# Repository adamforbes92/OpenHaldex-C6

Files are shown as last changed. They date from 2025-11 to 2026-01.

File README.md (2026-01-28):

# OpenHaldex - ESP32 C6
An open-source Generation 1, 2 & 4 Haldex Controller which originates/is a fork from ABangingDonk's 'OpenHaldex T4'.  It has been extended into Gen2 and Gen4 variants, with Gen3 and Gen5 currently unsupported - CAN reads of these systems would be awesome!

Originally based on the Teensy 4.0; the ESP32 C6 features two TWAI (CAN) interfaces as well as WiFi and Bluetooth support; which makes it an ideal candidate for easier interfacing.

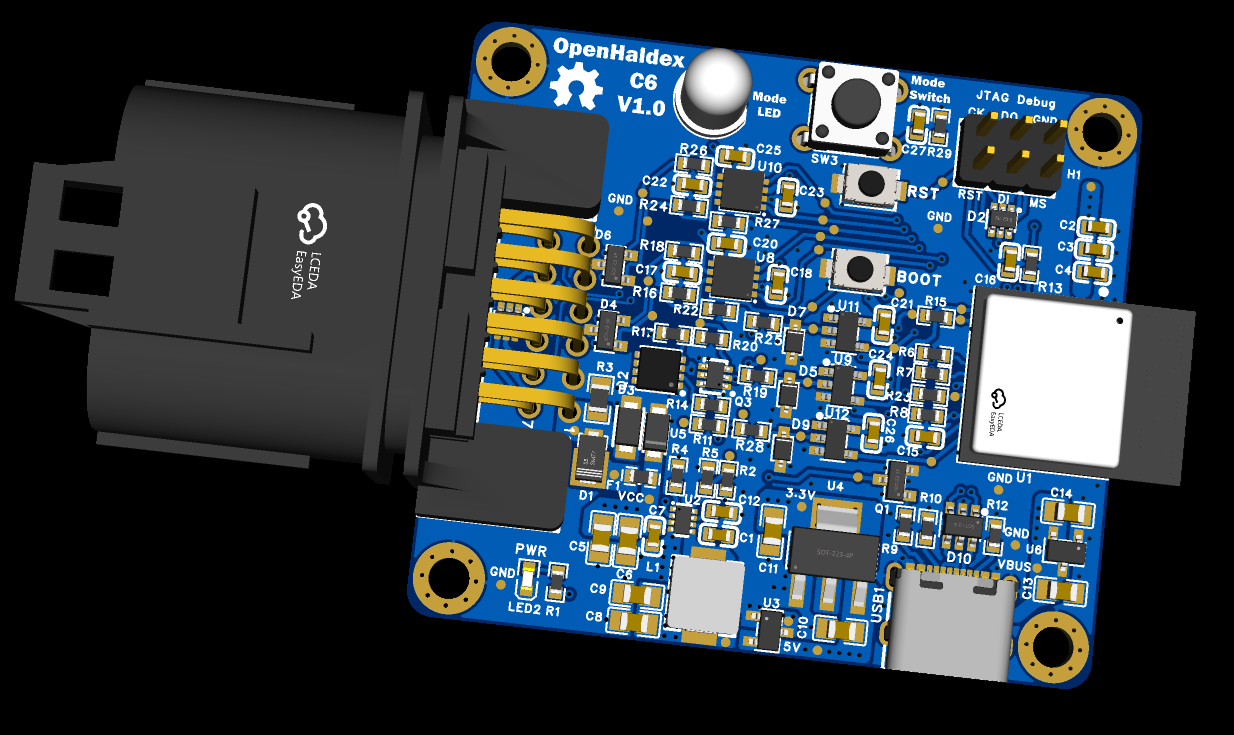
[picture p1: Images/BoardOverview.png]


### Purchase
If you want to purchase an assembled OpenHaldex C6 controller, you can do so here: [OpenHaldex C6 Controller - Forbes Automotive](https://forbes-automotive.com/products/openhaldex-controller)

### Concept
The basis of the module is to act as a middle man - read the incoming CAN frames destined for the OEM Haldex controller, and, if required, adjust these messages to 'trick' the Haldex into thinking more (or less) lock is required.  

Generation 1, 2 and 4 are all available as 'standalone' systems - which means that no other ECUs have to be present and OpenHaldex will create the necessary frames for Haldex operation.

### ESP32 C6
The ESP32 C6 features two TWAI controllers - which allows CANBUS messages to be read, processed and re-transmitted towards the Haldex.  It also supports WiFi and Bluetooth - which makes on-the-fly configuration changes possible.  

The original Teensy had an external HC-05 Bluetooth chip which is limited support wise - hence the decision to move to the ESP32.

### The Modes
The controller allows for 5 main modes: Stock (act as OEM), FWD (zero lock), 7525 (25% lock), 6040 (40% lock) and 5050 (100% lock) at the Haldex differential.  Generation 1, 2 and 4 have been tested on the bench to allow for a full understanding of what the stock CAN messages look like & therefore what messages need to be editted / created. 

These modes are displayed as colours using the 5mm PCB LED: Red (Stock), Green (FWD), Cyan (7525), Hot Pink (6040) and Blue (5050).  Custom modes are white.

#### Custom Modes
Custom modes allows the user to set up 1x specific lock points at either speed, throttle or both ranges.  Future additions will include multiple set points for varying degrees of lock at specific speed/throttle points.

The modes can be toggled with the onboard 'Mode' button, changed via. WiFi or via. CAN.

Disabling at low throttle inputs or high speed inputs are also configurable.

#### Changing Modes via. CAN
The modes can be changed via. CAN if required.  This is always enabled.  

Byte 0 should be sent with the required mode number (noting numbers below).  The remaining 7 bytes are unused (for just now...).

#### Mode Numbers
Current mode (Byte 0) assumes (uint8_t type):
```
  Stock = 0
  FWD = 1,
  5050 = 2,
  6040 = 3,
  7525 = 4,
  Custom = 5,
```
#### Receiving Modes via. CAN
The default CAN address for broadcasting current state is on 0x6B0.  If you enable 'Broadcast OpenHaldex' you may find there are clashes on the CAN network if an existing module is also broadcasting on this access.  This ID can be adjusted to suit.  It is deliberately a 'high' value because the default Bosch IDs have non-important devices set with high value IDs.  

The following data is broadcast onto the CAN network.  This could be used for aftermarket ECUs / clusters where there is a requirement to view current Haldex state:
```
    data[1] = isGen1Standalone + isGen2Standalone + isGen4Standalone;  // if is standalone.  Not used, but here for something to do
    data[2] = (uint8_t)received_haldex_engagement_raw;                 // processed/mapped by FISCuntrol
    data[3] = (uint8_t)lock_target;                                    // the lock % requested
    data[4] = received_vehicle_speed;                                  // the vehicle speed
    data[5] = state.mode_override;                                     // if is in 'override' mode
    data[6] = (uint8_t)state.mode;                                     // current mode (as above)
    data[7] = (uint8_t)received_pedal_value;                           // vehicle pedal value
```
### WiFi Setup
WiFi setup and configuration is always active.  Connect to 'OpenHaldex-C6' by searching in WiFi devices and searching for 192.168.1.1 in a browser.  All settings are available for editing.  Should the WiFi page hang, a long press on the 'mode' button will reset the WiFi connection.

## Installation
The controller uses an MX23A26NF1 connector.  The matching female connector is MX23A12SF1.  

### Optional Plug & Play Harness
For users choosing the optional plug & play harness, installation is quick and easy.  Remove the existing 6 pin connector at the differential and route the OEM cable back into the boot space.  Install the long end of the harness through the boot floor and connect to the differential.  The remaining small end connects back onto the OEM harness (previously fed through the boot floor) and the OpenHaldex module connected to it's connector.  Removal is opposite of installation.

Users without the optional plug & play harness will be required to make the following connections to Power/Ground/CAN:

### Pinouts
The pins for installation (without the plug'n'play harness) is as follows:
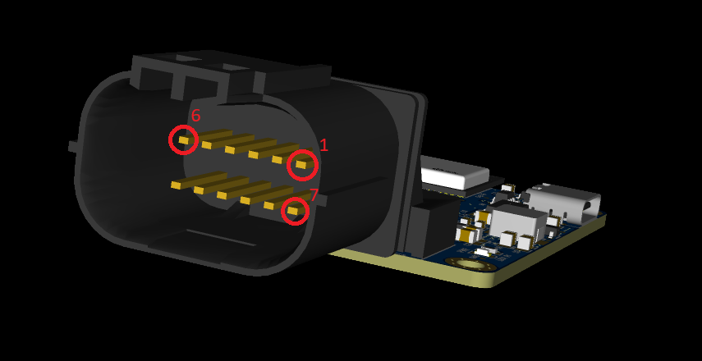
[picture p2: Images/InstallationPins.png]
InstallationPins-C6


The MX23A12NF connector pinout is:
| Pin/ | Signal | Notes |
|-----|---|---|
| 1 | Vbatt | 12 V |
| 2 | Ground/MALT | — |
| 3 | Chassis CAN Low | to Chassis/ECU side |
| 4 | Chassis CAN High | to Chassis/ECU side |
| 5 | Haldex CAN Low | to Haldex side |
| 6 | Haldex CAN High | to Haldex side |
| 7 | Switch Mode External | +12v to activate |
| 8 | Brake Switch In | +12v to activate |
| 9 | Brake Switch Out | Gen1 differentials ONLY |
| 10 | Handbrake Switch In | +12v to activate |
| 11 | Handbrake Switch Out | Gen1 differentials ONLY |

### Uploading Code
For users wishing to customise or edit the code, it is released here for free use.  Connect the Haldex controller via. a data USB-C cable (note some are ONLY power, so this needs to be checked).

It is recommended to check back here regularly to find updates, submit bugs or feature requests.

### Over The Air Updates
Over the air updates have been implemented and the process is as follows:

> Download the most recent 'Release' - this will be saved locally on your phone/laptop/etc as a '.bin'.
> Connect to OpenHaldex on WiFi
> Go to 192.168.1.1:81/update
>> Username: admin
>> Password: haldex
> Select file - locate the new '*.bin'
> Wait for ESP to reboot
> Re-connect and check the OTA tab for firmware version - this should match the downloaded Releases file

### CAN Sniffing / SavvyCAN
For a dedicated SavvyCAN interface, users can choose 'Analyzer Mode' in 'Setup'.  This will allow the Haldex Controller to act as a CAN sniffer so that CAN frames can be captured from either bus.  Once Analyzer mode is enabled, ALL Haldex control will be disabled and the system will operate in 'OEM' mode.

#### Connecting SavvyCAN (GVRET)
> 1. Keep the OpenHaldex Wi-Fi AP connected.
> 2. In SavvyCAN: **Add New Device Connection** -> **Network Connection (GVRET)**.
> 3. IP address: `192.168.1.1` (port 23 is implicit in SavvyCAN's GVRET UI).
> 4. Set CAN speed to `500000`.

### The PCB & Enclosure
The Gerber files for the PCB, should anyone wish to build their own, is under the "PCB" folder.  This is the latest board.
Similarly, the enclosures are also here.

>Pinout & functionality remains the same for ALL generations of enclosure.

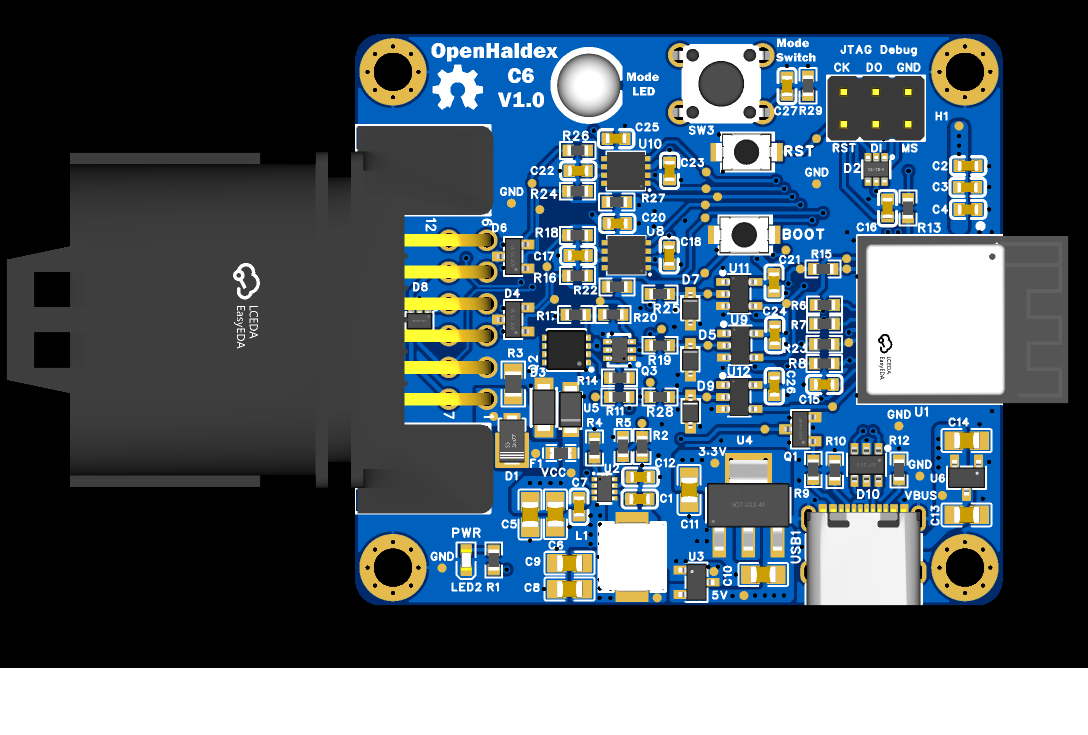
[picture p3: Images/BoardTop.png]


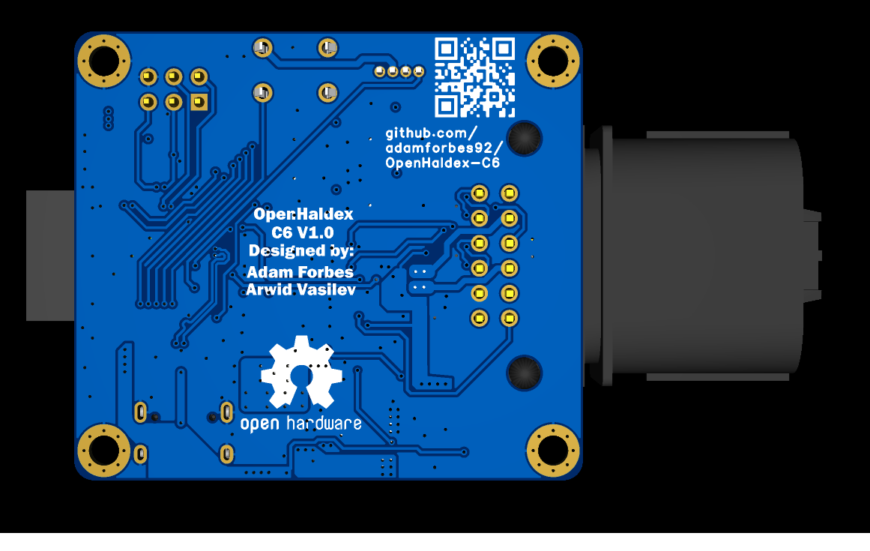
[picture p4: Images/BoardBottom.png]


### Nice to Haves
Flashing LED if there is an issue with writing CAN messages.

### Shout Outs
Massive thanks to Arwid Vasilev for re-designing the PCB!  Now on V1.02!
Massive thanks to LVT Technologies for adding in OTA updates - it's been something I've wanted to do for ages and this guy cracks it without question!  This'll make updating so much easier!  Cheers dude!

## Disclaimer
It should be noted that this will modify Haldex operation and therefore can only be operated off-road and on a closed course.  

It should always be assumed that the unit may crash/hang or cause the Haldex to operate unprediably and caution should be exercised when in use.

Using this unit in any way will exert more strain on drivetrain components, and while the OEM safety features are still in place, it should be understood that having the Haldex unit locked up permanently may cause acceleated wear.

Forbes-Automotive takes no responsiblity for damages as a result of using this unit or code in any form.

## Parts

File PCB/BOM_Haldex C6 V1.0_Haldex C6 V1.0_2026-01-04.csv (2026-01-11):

No. | Quantity | Comment | Designator | Footprint | Value | Manufacturer Part | Manufacturer | Supplier Part | Supplier
1 | 8 | 100nF | C1,C4,C12,C13,C14,C17,C21,C22 | C0603 | 100nF | CL10B104KB8NNNC | SAMSUNG(三星) | C1591 | LCSC
2 | 5 | 22uF | C2,C3,C7,C10,C11 | C0805 | 22uF | HGC0805R5226M350NSLJ | Chinocera(华瓷) | C22367832 | LCSC
3 | 3 | 47uF | C5,C6,C8 | C0805 | 47uF | CL21A476MPYNNWE | SAMSUNG(三星) | C5596752 | LCSC
4 | 1 | 33nF | C9 | C0603 | 33nF | CL10B333KB8NNNC | SAMSUNG(三星) | C21117 | LCSC
5 | 1 | 4.7uF | C15 | C0603 | 4.7uF | CL10A475KP8NNNC | SAMSUNG(三星) | C1705 | LCSC
6 | 1 | 2.2uF | C16 | C0603 | 2.2uF | CL10A225KO8NNNC | SAMSUNG(三星) | C23630 | LCSC
7 | 3 | 1uF | C18,C23,C24 | C0603 | 1uF | CL10B105KB8NQNC | SAMSUNG(三星) | C5199872 | LCSC
8 | 2 | 2.2nF | C19,C20 | C0603 | 2.2nF | CL10C222JB8NNNC | SAMSUNG(三星) | C33353 | LCSC
9 | 1 | SS3P3-M3/84A | D1 | DO-220AA_L3.4-W2.0-LS3.9-RD |  | SS3P3-M3/84A | VISHAY(威世) | C2920641 | LCSC
10 | 1 | SMF24CA | D2 | SOD-123FL_L2.8-W1.8-LS3.7-BI |  | SMF24CA | 晶导微电子 | C353294 | LCSC
11 | 1 | USBLC6-2SC6 | D3 | SOT-23-6_L2.9-W1.6-P0.95-LS2.8-BL |  | USBLC6-2SC6 | UMW(友台半导体) | C2687116 | LCSC
12 | 3 | BZT52C4V7S | D4,D6,D7 | SOD-323_L1.8-W1.3-LS2.5-RD |  | BZT52C4V7S | 晶导微电子 | C353517 | LCSC
13 | 1 | SMF12CT1G | D5 | SOT-363_L2.0-W1.3-P0.65-LS2.1-BR |  | SMF12CT1G | TECH PUBLIC(台舟) | C2999118 | LCSC
14 | 1 | SMF05C | D8 | SC-70-6_L2.0-W1.3-P0.65-LS2.1-BR |  | SMF05C | TECH PUBLIC(台舟) | C558425 | LCSC
15 | 2 | PESD2CAN | D9,D10 | SOT-23-3_L2.9-W1.3-P1.90-LS2.4-BR |  | PESD2CAN | TECH PUBLIC(台舟) | C907830 | LCSC
16 | 1 | SMF24A | D11 | SOD-123FL_L2.7-W1.8-LS3.8-RD |  | SMF24A | R+O(宏嘉诚) | C19077514 | LCSC
17 | 1 | 0467001.NRHF | F1 | F0603 |  | 0467001.NRHF | Littelfuse(美国力特) | C151139 | LCSC
18 | 1 | 2.54-2*3 | H1 | HDR-TH_6P-P2.54-V-R2-C3-S2.54_A2541WV-2X3P |  | 2.54-2*3 | ZHOURI(洲日) | C5116479 | LCSC
19 | 1 | 3.3uH | L1 | IND-SMD_L5.4-W5.2_RS0530 | 3.3uH | RS0530-3R3MS | Ruishen(瑞申电子) | C32712971 | LCSC
20 | 1 | XL-1608UGC-04 | LED1 | LED0603-RD_GREEN |  | XL-1608UGC-04 | XINGLIGHT(成兴光) | C965804 | LCSC
21 | 1 | WS2812D-F5 | LED2 | LED-TH_4P-BD5.8-P1.30 |  | WS2812D-F5 | worldsemi | C190565 | LCSC
22 | 1 | MX23A12NF1 | P1 | COON-TH_MX23A12NF1 |  | MX23A12NF1 | JAE(日本航空电子) | C5359486 | LCSC
23 | 1 | AGM30P14MBP | Q1 | DFN-8_L3.2-W3.1-P0.65-LS3.4-BL-1 |  | AGM30P14MBP | AGMSEMI(芯控源) | C5367089 | LCSC
24 | 1 | 2N7002DW | Q2 | SOT-363-6_L2.0-W1.3-P0.65-LS2.1-BL |  | 2N7002DW | Hottech(合科泰) | C5190214 | LCSC
25 | 6 | 1kΩ | R1,R8,R9,R11,R13,R16 | R0603 | 1kΩ | 0603WAF1001T5E | UNI-ROYAL(厚声) | C21190 | LCSC
26 | 1 | 280pF@1MHz | R2 | R0805 | 280pF@1MHz | FPV201209E260PKT | FH(风华) | C2991545 | LCSC
27 | 1 | 52.3kΩ | R3 | R0603 | 52.3kΩ | 0603WAF5232T5E | UNI-ROYAL(厚声) | C23198 | LCSC
28 | 3 | 20kΩ | R4,R10,R14 | R0603 | 20kΩ | 0603WAF2002T5E | UNI-ROYAL(厚声) | C4184 | LCSC
29 | 8 | 10kΩ | R5,R12,R15,R17,R20,R25,R26,R27 | R0603 | 10kΩ | 0603WAF1002T5E | UNI-ROYAL(厚声) | C25804 | LCSC
30 | 2 | 5.1kΩ | R6,R7 | R0603 | 5.1kΩ | 0603WAF5101T5E | UNI-ROYAL(厚声) | C23186 | LCSC
31 | 2 | 33Ω | R18,R19 | R0603 | 33Ω | 0603WAF330JT5E | UNI-ROYAL(厚声) | C23140 | LCSC
32 | 4 | 60.4Ω | R21,R22,R23,R24 | R0603 | 60.4Ω | RC0603FR-0760R4L | YAGEO(国巨) | C245987 | LCSC
33 | 1 | TS-1002-07026 | SW1 | SW-TH_4P-L6.0-W6.0-P4.50-LS6.5 |  | TS-1002-07026 | XUNPU(讯普) | C455095 | LCSC
34 | 2 | TS-1088-AR02016 | SW2,SW3 | SW-SMD_L3.9-W3.0-P4.45 |  | TS-1088-AR02016 | XUNPU(讯普) | C720477 | LCSC
35 | 1 | TPS62933DRLR | U1 | SOT-583-8_L2.1-W1.2-P0.50-LS1.6-BR |  | TPS62933DRLR | TI(德州仪器) | C3200405 | LCSC
36 | 2 | CH213K | U2,U5 | SOT-23-3_L2.9-W1.6-P1.90-LS2.8-BR |  | CH213K | WCH(南京沁恒) | C5456874 | LCSC
37 | 1 | AMS1117-3.3 | U3 | SOT-223-4_L6.5-W3.5-P2.30-LS7.0-BR |  | AMS1117-3.3 | UMW(友台半导体) | C347222 | LCSC
38 | 3 | SN74LVC1G17DBVR | U6,U7,U8 | SOT-23-5_L3.0-W1.5-P0.95-LS2.8-BL |  | SN74LVC1G17DBVR | TECH PUBLIC(台舟) | C19829662 | LCSC
39 | 1 | ESP32-C6-MINI-1-N4 | U9 | WIFIM-SMD_61P-L16.6-W13.2-P0.80-ESP32-C6-MINI-1-N4 |  | ESP32-C6-MINI-1-N4 | ESPRESSIF(乐鑫) | C5736265 | LCSC
40 | 2 | TCAN1044VDRBRQ1 | U10,U11 | VSON-8_L3.0-W3.0-P0.65-BR-EP |  | TCAN1044VDRBRQ1 | TI(德州仪器) | C5215851 | LCSC
41 | 1 | TYPE-C 16PIN 2MD(073) | USB1 | USB-C-SMD_TYPE-C-6PIN-2MD-073 |  | TYPE-C 16PIN 2MD(073) | SHOU HAN(首韩) | C2765186 | LCSC

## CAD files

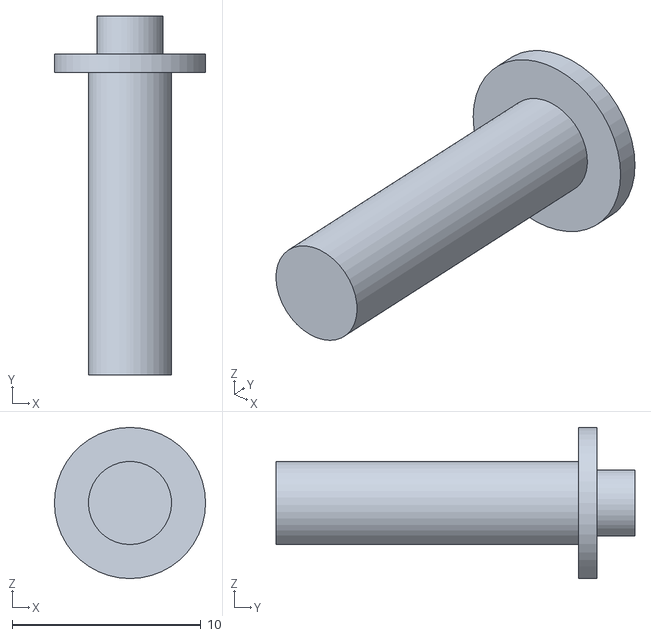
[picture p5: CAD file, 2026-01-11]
Enclosure/HaldexButtonV4.STL
8.00 x 19.0 x 8.00

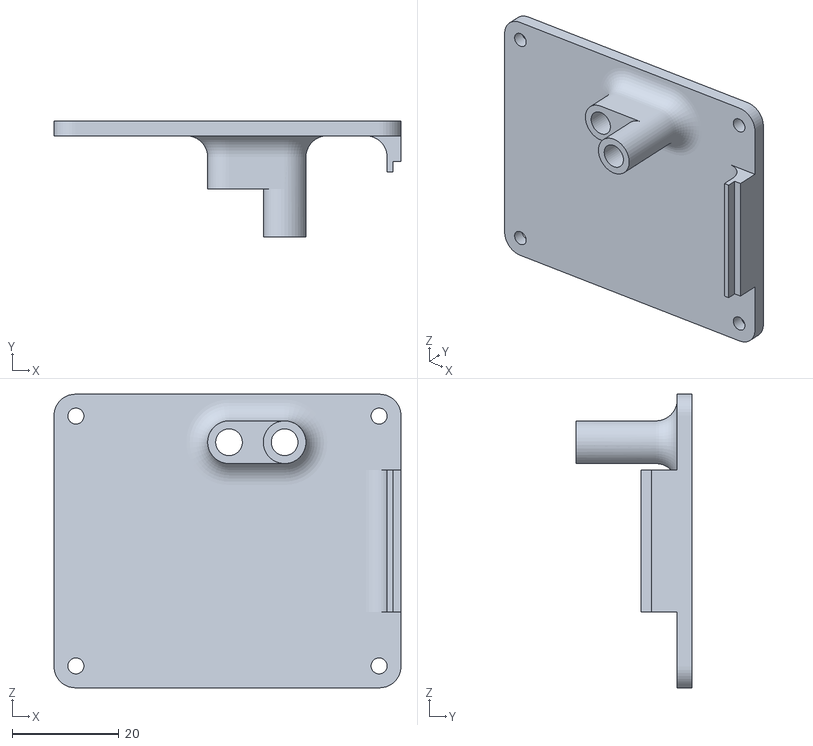
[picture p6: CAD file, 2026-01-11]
Enclosure/HaldexBoxC6_V1_Lid.STL
65.0 x 21.8 x 55.0

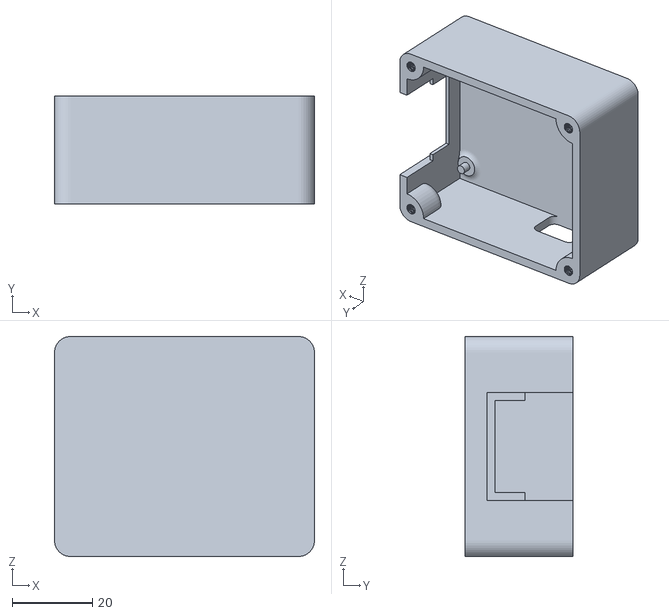
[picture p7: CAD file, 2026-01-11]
Enclosure/HaldexBoxC6_V1.STL
65.0 x 27.0 x 55.0

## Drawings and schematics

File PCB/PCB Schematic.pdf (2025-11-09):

Schematic | Haldex C6 V1.0 | Create at | 2025-11-05
Update at | 2025-11-09
Board | Haldex C6 V1.0 | Page | Power +USB
Drawn | | OpenHaldexC6-V1.01

# Reviewed

Version | Size | Page 1 Total 3
V1.0 | A4 | EasyEDA.com

VCC

GND
GND

ADJ(GND)

1 VOUT(TAB) 2
VIN 3
TAB 4

U4

AMS1117-3.3

Switching Regulator 6.5V to 24V ->5V

C6
22uF

C5
22uF

FB 8

SS 7

BST 6
SW 5
GND 4

VIN 3
EN 2
RT 1

U2

TPS62933DRLR

RT

SS

BST

SW
FB

F1
06H1100D VBAT_UF

VBAT

R3280pF@¹MHz
D3
SMF24CA

U5
SMF24A

L1
3.3uH

EN_TPS

Note:EN has internal pull-up Float=Enable
Low=Disable

C10
22uF

+3.3V

+5V

Input protection | Buck | LDO

GND

1

VO- 2

VI+ 3

U3

CH213K

BUCK_OUT

+5V

C8
47uF

C9
47uF

C11
47uF

20K on RT= 1.09MHz switching freq

PWR Indicator

C12
33nF

R2
52.3k

R4
20k

R5
10k

C1

100nF

C7
100nF

R1
1k

GND

USB_D+
USB_D-

CC1

CC2

GND 1
VBUS 2
SBU2 3
CC1 4
DN2 5
DP1 6
DN1 7
DP2 8
SBU1 9
CC2 10
VBUS 11
GND 12 SHELL 13

SHELL 14

USB1

TYPE-C 16PIN 2MD(073)

GND

VBUS

USB_D+

USB_D- | ESP_USB_D- ESP_USB_D+

USB Conenctor

USB Protection
I/O1 1
GND 2
I/O2 3

I/O2 4

VBUS 5

I/O1 6

D10

USBLC6-2SC6

GND

1

VO- 2

VI+ 3

U6 CH213K

VBUS

C14
22uF

C13
22uF

GND

VBUS

+5V

Q1
2N7002

GND

EN_TPS

TPS Disable on USB Power

BackFeed Protection

USB

Note: Remove 10K resistor (R9) if you dont want the USB plugging in to disable the VCC Power In

R10
5.1k
R12
5.1k

R9
10k

D1

SS3P3-M3/84A

Note: CH213K is reverse voltage protection diode with over-curent protection with 1A limit
As an added bonus its low Ron(around 160m ) creates a RC low pass filter
~ 100kHz due to MLCC capacity derating from voltage

As long as at 5V line stays above 4.5V all will work well

WARNING: DO NOT use LONG USB CABLES to power the device.

They use thin,long wires and will create a substatial voltage drop making the 5V supply line TOO LOW.

## If you MUST use a long USB cable remove R9 and power the module from 12V source via the PWR in and GND pins on the connector

The lower limit on the 5V line is 4.5V due to the LDO dropout voltage and the CAN tranciver

## both needing 4.5V minimum to work correctly Measure between the 5V and GND test points on the board to verify voltage You can measure USB voltage before protection diode on VBUS test point

LED2

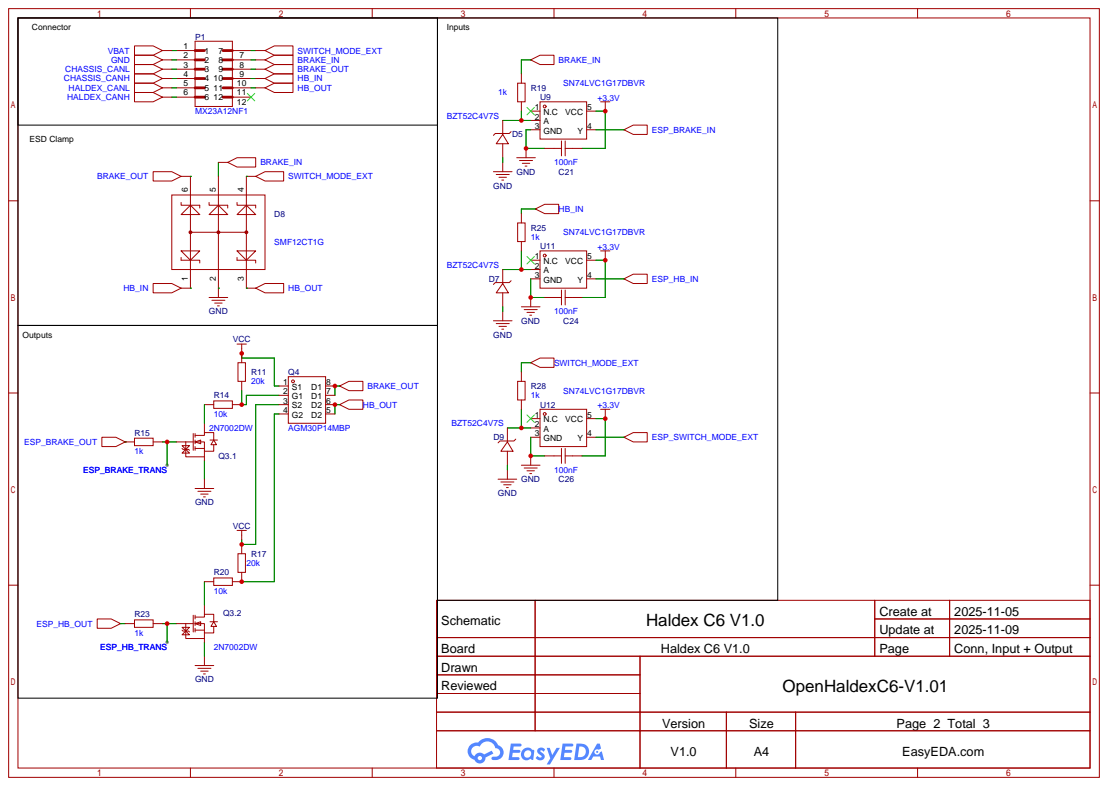
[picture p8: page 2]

Schematic | Haldex C6 V1.0 | Create at | 2025-11-05

Update at | 2025-11-09

Board | Haldex C6 V1.0 | Page | Conn, Input + Output
Drawn | | OpenHaldexC6-V1.01
Reviewed

IO21 27 IO22 28 IO23 29 RXD0 30 TXD0 31 NC 32 NC 33 NC 34 NC 35 GND 36 GND 37 GND 38 GND 39 GND 40 GND 41 GND 42 GND 43 GND 44 GND 45 GND 46 GND 47 GND 48 GND 49 GND 50 GND 51 GND 52 GND 53

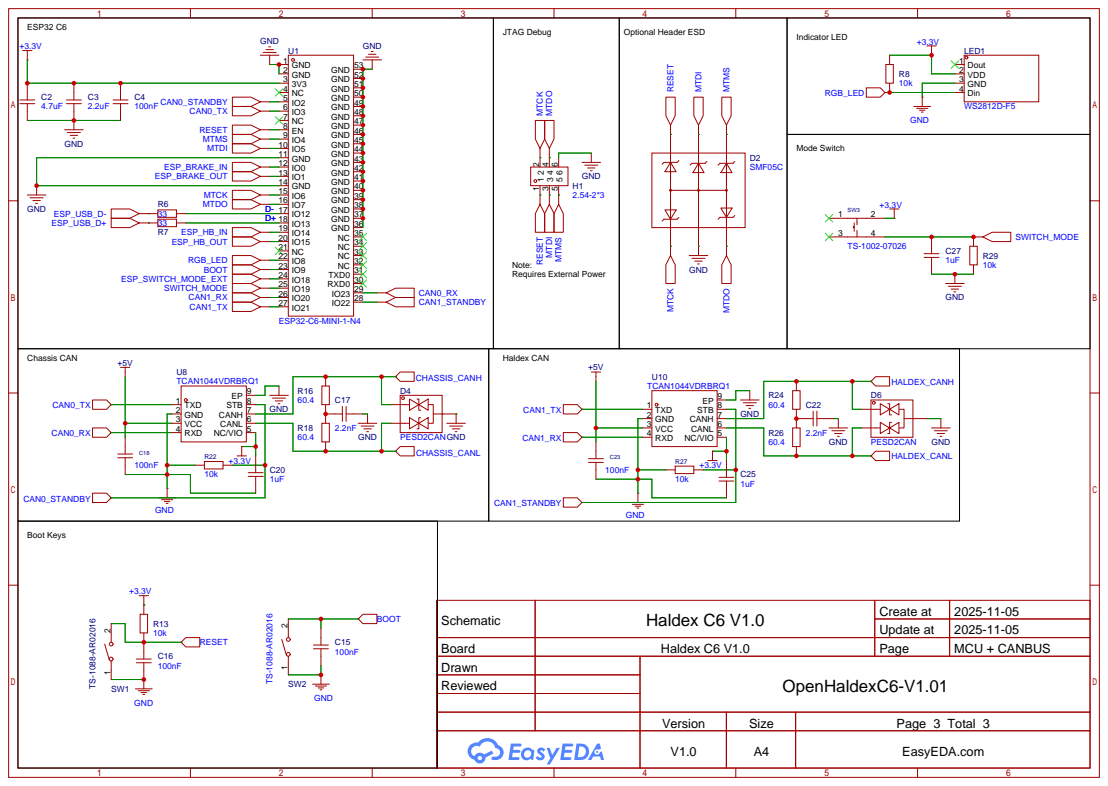
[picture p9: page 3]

Schematic | Haldex C6 V1.0 | Create at | 2025-11-05

Update at | 2025-11-05

Board | Haldex C6 V1.0 | Page | MCU + CANBUS
Drawn | | OpenHaldexC6-V1.01
Reviewed

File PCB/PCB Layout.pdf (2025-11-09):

## OpenHaldex

### RST

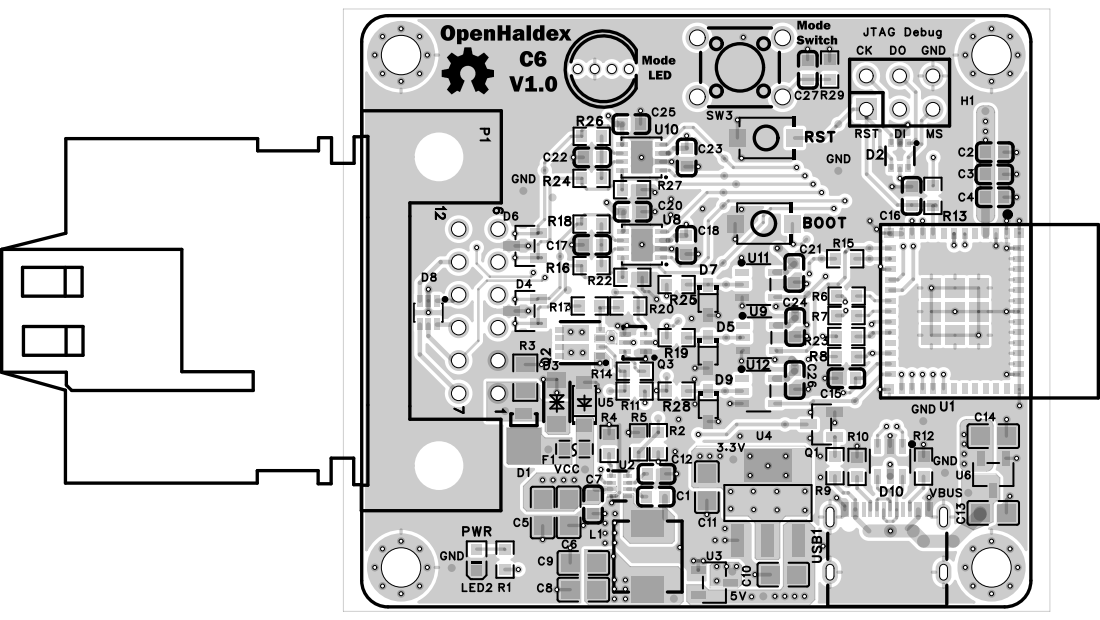
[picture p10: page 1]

## github.com/ adamforbes92/

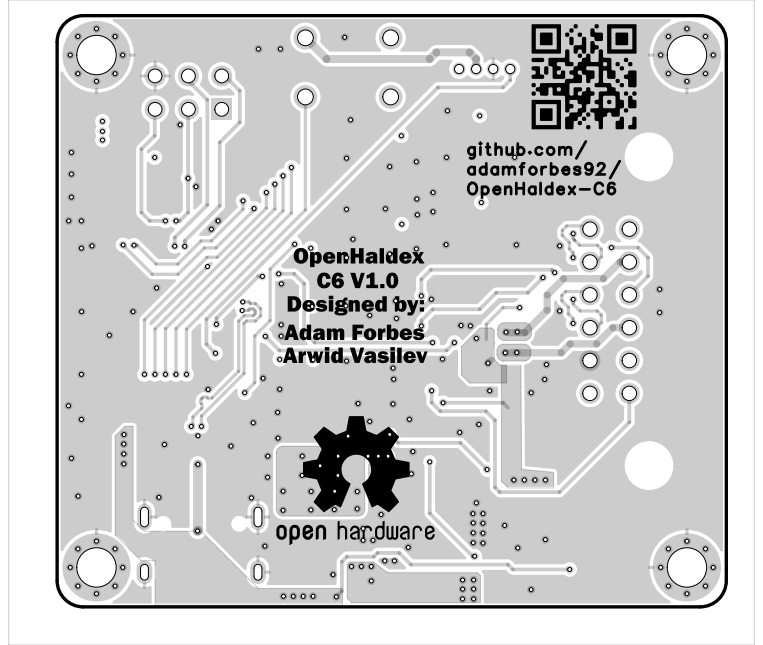
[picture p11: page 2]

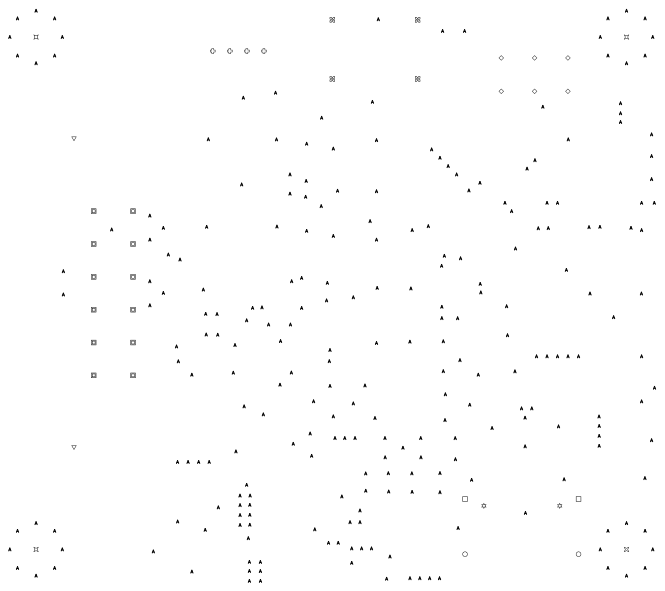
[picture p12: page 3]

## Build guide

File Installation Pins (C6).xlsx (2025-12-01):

Pin Number | Purpose | Comment
1 | 12v Ignition | Supply to module, 12v ignition
2 | Ground | Ground
3 | CAN L | Chassis CAN Low
4 | CAN H | Chassis CAN High
5 | CAN L | Haldex CAN Low
6 | CAN H | Haldex CAN High
7 | Mode Change | 12v switch to change mode
8 | Brake In | Brake signal in (+12v)
9 | Brake Out | Brake signal out
10 | Handbrake In | Handbrake signal in (+12v)
11 | Handbrake Out | Handbrake signal out
12 | N/A | N/A

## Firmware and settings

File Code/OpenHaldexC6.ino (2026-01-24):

/*
OpenHaldex-C6 - Forbes Automotive
Haldex Controller for Gen1, Gen2 and Gen4 Haldex Controllers.  Supports WiFi.  Version: 1.06.  Versions in '_ver.ino'

Codebase derived from OpenHaldex 4.0 - CAN data is the same, just ported to ESP32 C6.
*/

#include <OpenHaldexC6_defs.h>

// Current firmware version (must match OpenHaldexC6_ver.h)
#define FW_VERSION "1.10"

void setup() {
#if enableDebug || detailedDebug || detailedDebugCAN || detailedDebugWiFi || detailedDebugEEP || detailedDebugIO
  Serial.begin(500000);  // if ANY Serial is required, begin
  DEBUG("OpenHaldex-C6 Launching...");
#endif

  readEEP();       // read EEPROM for stored settings  - in '_EEP.ino'
  setupIO();       // setup gpio for input / output  - in '_io.ino'
  setupCAN();      // setup two CAN buses  - in '_io.ino'
  setupButtons();  // setup 'buttons' for changing mode (internal and external) - in '_io.ino'
  setupTasks();    // setup tasks for each of the main functions - CAN Chassis/Haldex handling, Serial prints, Standalone, etc - in '_io.ino'
  connectWifi();   // enable / start WiFi - in '_wifi.ino'
  setupUI();       // setup wifi user interface - in '_wifi.ino'
  setupOTA();      // setup OTA update server - in '_OTA.ino'
}

void loop() {
  delay(100);  // literally here to give more CPU time to tasks

  if (rebootWiFi) {
#if enableDebug
    DEBUG("Restarting WiFi...");
#endif

    for (int i = 0; i <= 3; i++) {
      strip.setLedColorData(led_channel, led_brightness, led_brightness, led_brightness);  // red
      strip.show();
      delay(50);
      strip.setLedColorData(led_channel, 0, 0, 0);  // red
      strip.show();
      delay(50);
    }

    WiFi.disconnect(true, true);
    WiFi.mode(WIFI_OFF);

    connectWifi();  // enable / start WiFi - in '_wifi.ino'
    //setupUI();      // setup wifi user interface - in '_wifi.ino'
    rebootWiFi = false;
  }
}

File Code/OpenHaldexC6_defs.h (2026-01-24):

// general ESP activities
#include <stdio.h>
#include <stdlib.h>
#include "freertos/FreeRTOS.h"
#include "freertos/task.h"
#include "freertos/semphr.h"
#include "esp_err.h"
#include "esp_log.h"
#include "driver/twai.h"
#include "driver/gpio.h"

// for CAN IDs - to make code easier
#include <OpenHaldexC6_canID.h>

#include "Freenove_WS2812_Lib_for_ESP32.h"  // for RGB LED
#include <Preferences.h>                    // for eeprom/remember settings

#include <ESPUI.h>    // included for WiFi pages
#include <WiFi.h>     // included for WiFi pages
#include <ESPmDNS.h>  // included for WiFi pages

#include "InterruptButton.h"  // for mode button (internal & external)

// debug options
#define enableDebug 0
#define detailedDebug 0
#define detailedDebugStack 0
#define detailedDebugRuntimeStats 0
#define detailedDebugCAN 0
#define detailedDebugWiFi 0
#define detailedDebugEEP 0
#define detailedDebugIO 0

// refresh rates
#define eepRefresh 2000            // EEPROM save in ms
#define broadcastRefresh 200       // broadcast refresh rate in ms
#define serialMonitorRefresh 1000  // Serial Monitor refresh rate in ms
#define labelRefresh 500           // broadcast refresh rate in ms
#define updateTriggersRefresh 500

// debugging macros
#ifdef enableDebug
#define DEBUG(x, ...) Serial.printf(x "\n", ##__VA_ARGS__)
#define DEBUG_(x, ...) Serial.printf(x, ##__VA_ARGS__)
#else
#define DEBUG(x, ...)
#define DEBUG_(x, ...)
#endif

// helpers to format a number as a binary string for printf
#define BYTE_TO_BINARY_PATTERN "%c%c%c%c%c%c%c%c"
#define BYTE_TO_BINARY(byte) \
  ((byte)&0x80 ? '1' : '0'), \
    ((byte)&0x40 ? '1' : '0'), \
    ((byte)&0x20 ? '1' : '0'), \
    ((byte)&0x10 ? '1' : '0'), \
    ((byte)&0x08 ? '1' : '0'), \
    ((byte)&0x04 ? '1' : '0'), \
    ((byte)&0x02 ? '1' : '0'), \
    ((byte)&0x01 ? '1' : '0')

// GPIO
#define CAN0_RS 2   // can_0 slope control
#define CAN0_RX 23  // can_0 rx
#define CAN0_TX 3   // can_0 tx
#define CAN1_RS 22  // can_1 slope control
#define CAN1_RX 20  // can_1 tx
#define CAN1_TX 21  // can_1 rx

#define gpio_led 8        // gpio for led
#define gpio_mode 19      // gpio mode button internal
#define gpio_mode_ext 18  // gpio mode button external

#define gpio_hb_in 14     // gpio for handbrake signal in
#define gpio_hb_out 15    // gpio for handbrake signal out
#define gpio_brake_in 0   // gpio for brake signal in
#define gpio_brake_out 1  // gpio for brake signal out

// led settings
#define led_channel 0       // channel for led
#define led_brightness 255  // default brightness

// wifi settings
#define wifiHostName "OpenHaldex-C6"  // the WiFi name

static twai_handle_t twai_bus_0;  // for ESP32 C6 CANBUS 0
static twai_handle_t twai_bus_1;  // for ESP32 C6 CANBUS 1

twai_message_t rx_message_hdx;  // incoming haldex message
twai_message_t rx_message_chs;  // incoming chassis message

twai_message_t tx_message_hdx;  // outgoing haldex message
twai_message_t tx_message_chs;  // outgoing chassis message

TaskHandle_t handle_frames1000;  // for enabling/disabling 1000ms frames
TaskHandle_t handle_frames200;   // for enabling/disabling 200ms frames
TaskHandle_t handle_frames100;   // for enabling/disabling 100ms frames
TaskHandle_t handle_frames25;    // for enabling/disabling 25ms frames
TaskHandle_t handle_frames20;    // for enabling/disabling 20ms frames
TaskHandle_t handle_frames10;    // for enabling/disabling 10ms frames

// setup - main inputs
bool isMPH = false;       // 0 = kph, 1 = mph
#define mphFactor 621371  // to convert from kmh > mph

// for EEP
Preferences pref;  // for EEPROM / storing settings

// for LED
Freenove_ESP32_WS2812 strip = Freenove_ESP32_WS2812(1, gpio_led, led_channel, TYPE_RGB);  // 1 led, gpio pin, channel, type of LED

// for mode changing (buttons & external inputs)
InterruptButton btnMode(gpio_mode, HIGH, GPIO_MODE_INPUT, 1000, 500, 750, 80000);          // pin, GPIO_MODE_INPUT, state when pressed, long press, autorepeat, double-click, debounce
InterruptButton btnMode_ext(gpio_mode_ext, HIGH, GPIO_MODE_INPUT, 1000, 500, 750, 80000);  // pin, GPIO_MODE_INPUT, state when pressed, long press, autorepeat, double-click, debounce

// functions
void frames10();
void frames20();
void frames25();
void frames100();
void frames200();
void frames1000();

void parseCAN_chs();
void parseCAN_hdx();
void broadcastOpenHaldex();
void showHaldexState();

void setupButtons();
void setupCAN();
void setupTasks();

void updateTriggers();
void modeChange();
void modeChangeExt();

extern void getLockData(twai_message_t &rx_message_chs);
extern uint8_t get_lock_target_adjusted_value(uint8_t value, bool invert);

// for EEP
extern void readEEP();
extern void writeEEP();

// for WiFi Function Prototypes
extern void connectWifi();
extern void disconnectWifi();
extern void setupUI();
extern void generalCallback(Control *sender, int type);
extern void extendedCallback(Control *sender, int type, void *param);
extern void updateLabels();
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

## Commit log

2025-12-01 Installation Pins
    Added
    [Installation Pins (C6).xlsx]
2026-01-01 V1.04
    V1.04 - added feedback for incoming brake/handbrake sensors. Added options to invert if required.
    [OpenHaldexC6.ino, OpenHaldexC6_EEP.ino, OpenHaldexC6_IO.ino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]
2026-01-11 V1.05
    Added enclosure and fixed brake output
    [BOM_Haldex C6 V1.0_Haldex C6 V1.0_2026-01-04.csv, HaldexBoxC6_V1.STL, HaldexBoxC6_V1_Lid.STL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]
2026-01-12 V1.07
    Added 60/40 & custom modes. Added OTA.
    [partitions.csv]
2026-01-20 V1.08
    Fixed WiFi Hang
    [OpenHaldexC6.ino, OpenHaldexC6_Calculations.ino, OpenHaldexC6_OTA.ino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]
2026-01-24 V1.09
    V1.09 - revised throttle AND speed setpoints to work together with enable/disable lock - thanks to Chris!
2026-01-25 added can frame analyzer function
2026-01-26 Revert "Merge pull request #6 from meatro/oem-pcb"
    This reverts commit e3488b3ce1aab9debf1c56b08cc4bf413192822b, reversing
    changes made to 0dc466d7d08361c34deca4feba08efb691707ea5.
    [OpenHaldexC6_IO.ino, OpenHaldexC6_WiFi.ino, OpenHaldexC6_can.ino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]
